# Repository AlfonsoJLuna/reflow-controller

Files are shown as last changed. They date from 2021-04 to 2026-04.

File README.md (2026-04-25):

# Reflow Controller

Open-source reflow controller for ovens and hot plates.

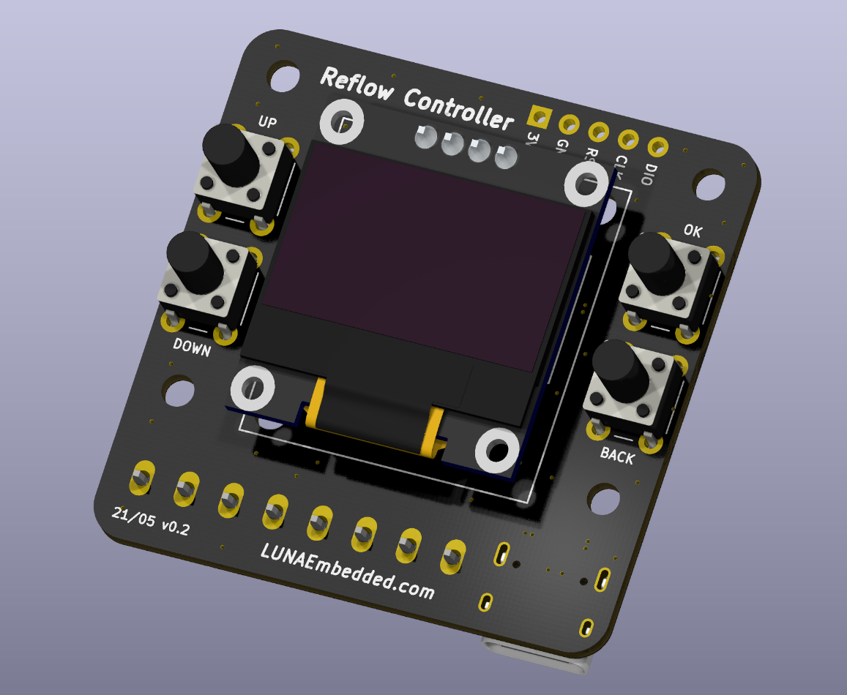
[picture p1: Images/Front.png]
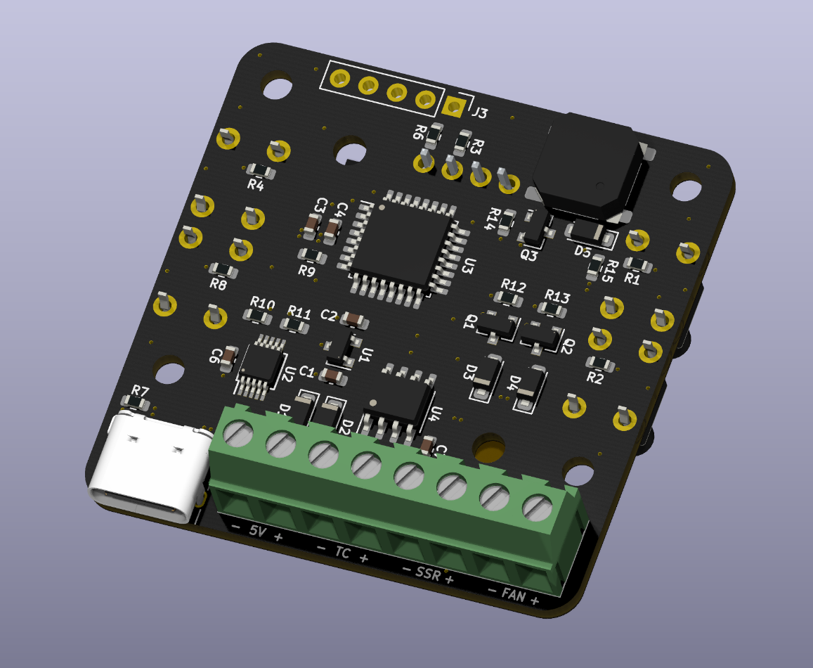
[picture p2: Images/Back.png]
 | 
:---: | :---:
Front | Back

## Features

* MCU: STM32G030K6T6
* CH340E USB-Serial converter.
* Sensors: K-Type thermocouple to digital converter. Compatible with both MAX31855 and MAX6675.
* Display: SSD1306 128×164 0.96" OLED.
* Inputs: 4x Push buttons to navigate the menu.
* Outputs: 2x 5V 300mA outputs. Capable of driving solid state relays as well as inductive loads (mechanical relays, fans).
* Buzzer: Alarm buzzer.
* Power: 5V provided via USB-C or screw terminals.

## Related repositories

Firmware for this project lives in [reflow-controller-fw](https://github.com/AlfonsoJLuna/reflow-controller-fw).

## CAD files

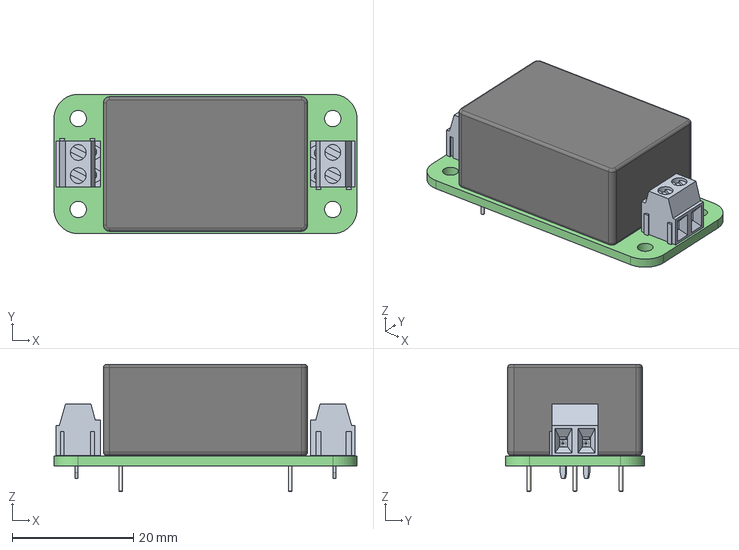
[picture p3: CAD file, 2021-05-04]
Hardware/AC-DC/AC-DC.step
50.0 x 23.0 x 21.0 mm

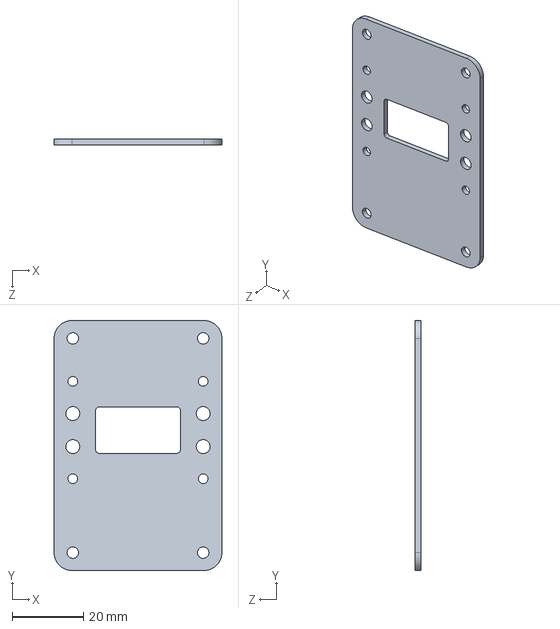
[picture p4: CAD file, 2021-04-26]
Hardware/Front Panel/Generic Oven/Generic_Oven.step
47.0 x 70.0 x 1.60 mm

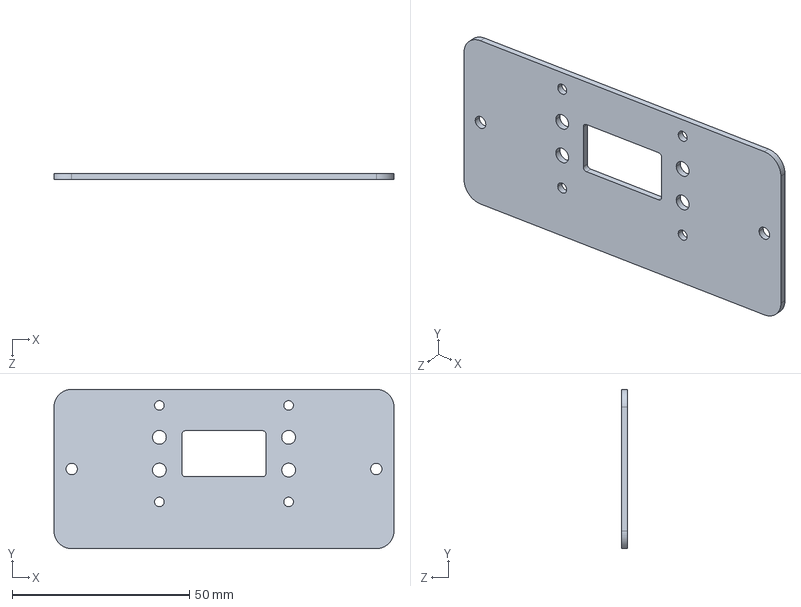
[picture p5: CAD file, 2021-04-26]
Hardware/Front Panel/Uyue 946-1010/Uyue_946_1010.step
96.0 x 45.0 x 1.60 mm

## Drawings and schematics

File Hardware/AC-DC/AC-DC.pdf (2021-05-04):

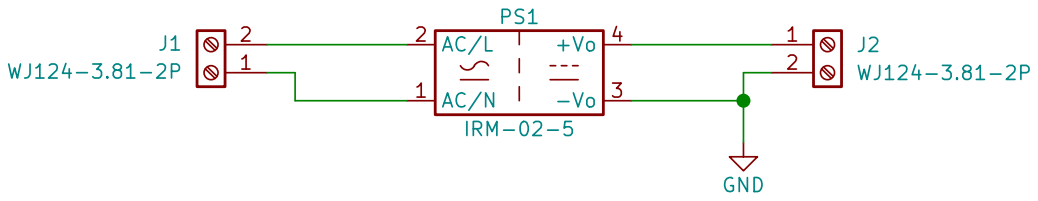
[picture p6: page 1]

File: AC-DC.sch Sheet: / LUNAEmbedded.com

Id: 1/1 Title: AC/DC Converter Module

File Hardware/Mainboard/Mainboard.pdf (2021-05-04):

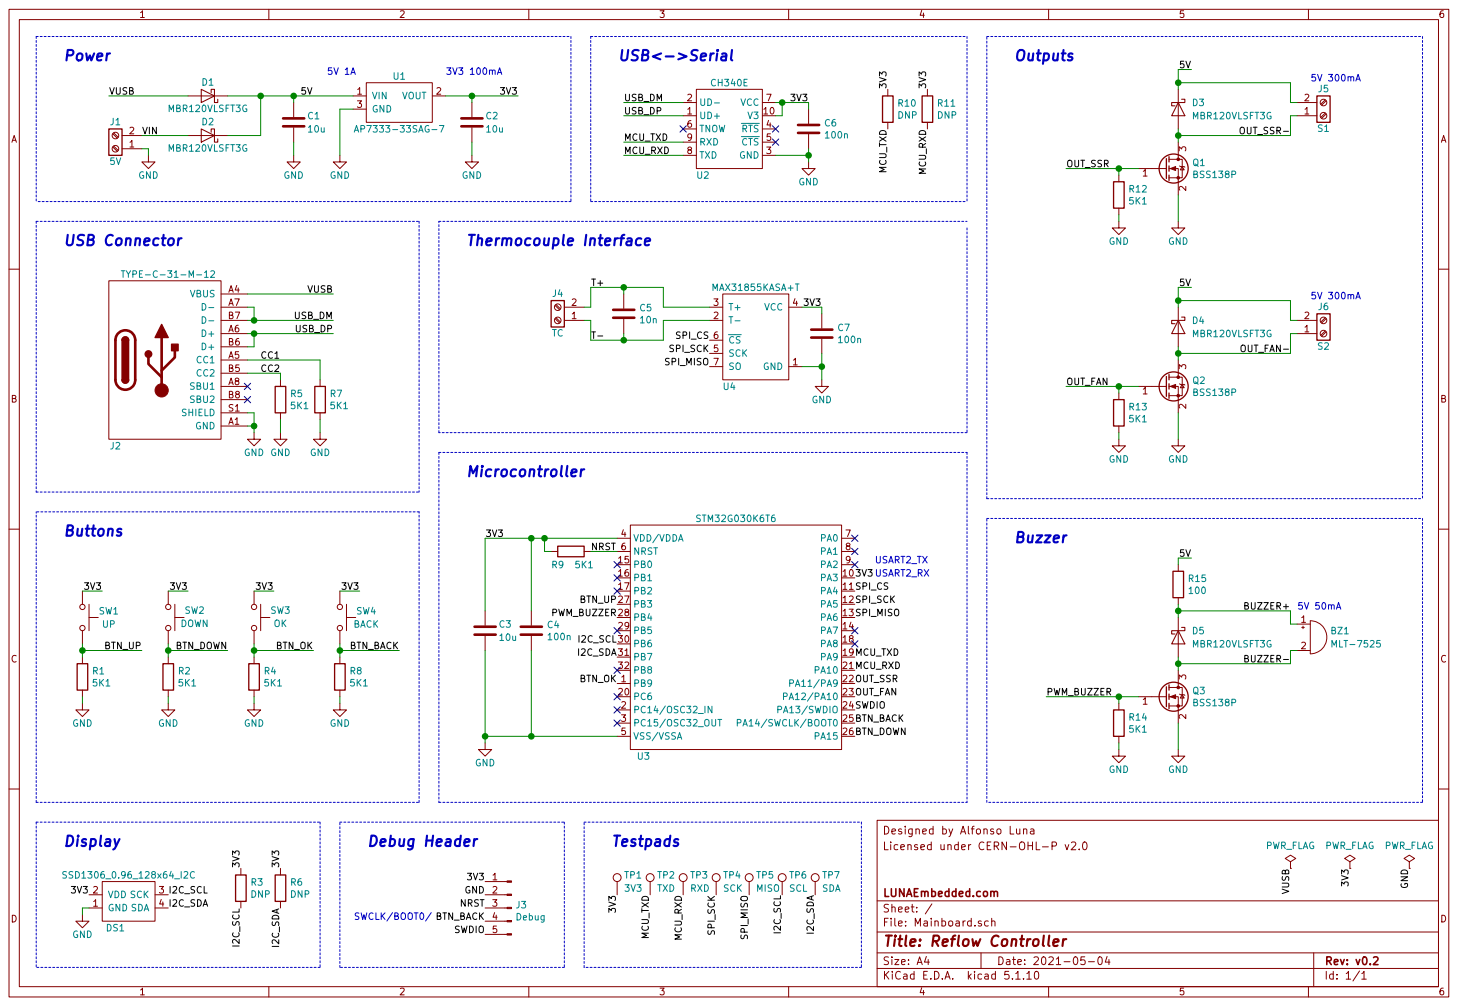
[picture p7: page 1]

Licensed under CERN-OHL-P v2.0 Designed by Alfonso Luna

Id: 1/1 Title: Reflow Controller File: Mainboard.sch Sheet: / LUNAEmbedded.com

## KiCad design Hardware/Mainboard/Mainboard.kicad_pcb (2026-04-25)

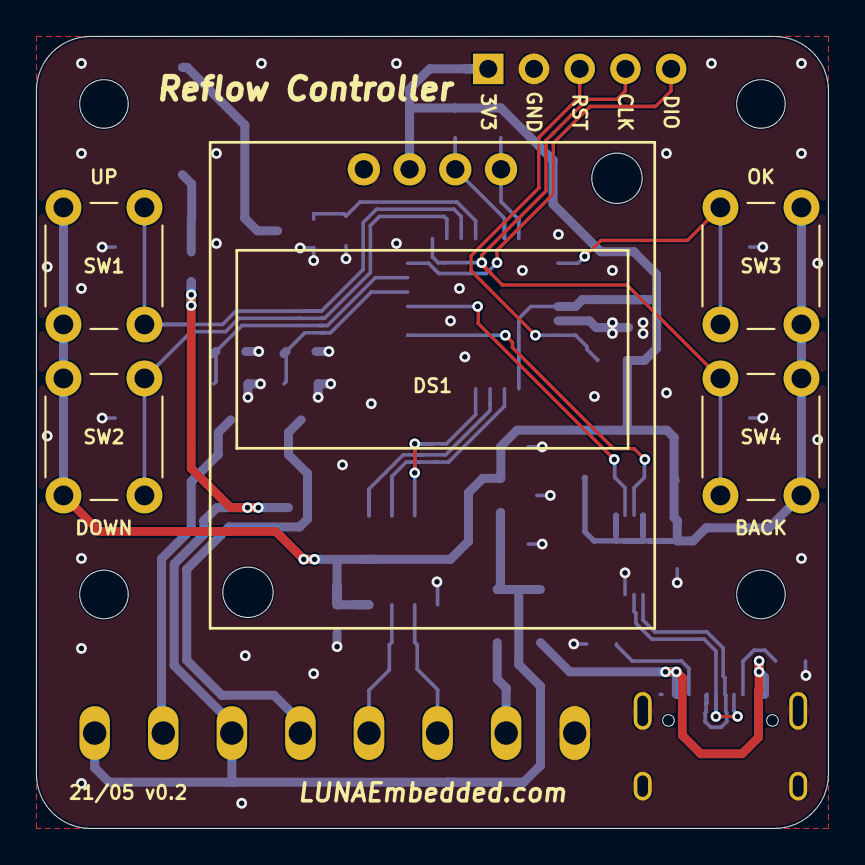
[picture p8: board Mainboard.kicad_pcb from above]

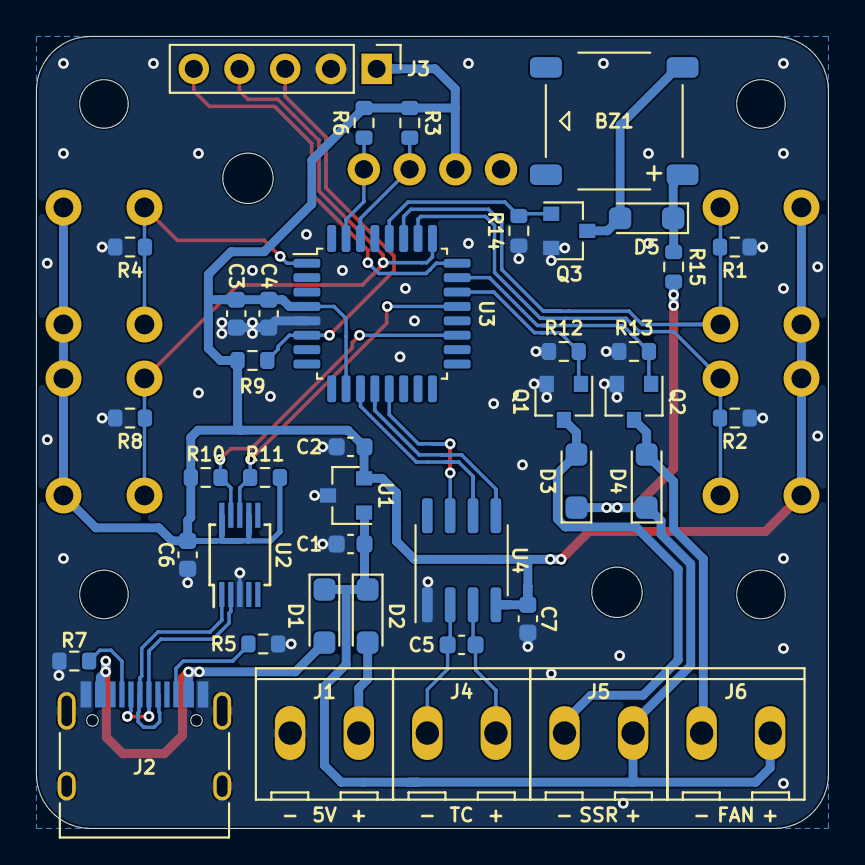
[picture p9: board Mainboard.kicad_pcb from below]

Board: 2 copper layers, 44.0 x 44.0 mm, 46 parts (41 on the bottom side), 31 nets.

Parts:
BZ1: MLT-7525
C1, C2, C3: 10u; C_0603_1608Metric
C4, C6, C7: 100n; C_0603_1608Metric
C5: 10n; C_0603_1608Metric
D1, D2, D3, D4, D5: MBR120VLSFT3G; SOD-123FL
DS1: SSD1306_0.96_128x64_I2C
J1: 5V; WJ124-3.81-2P
J2: TYPE-C-31-M-12; USB_C_Receptacle_HRO_TYPE-C-31-M-12
J3: Debug; PinHeader_1x05_P2.54mm_Vertical
J4: TC; WJ124-3.81-2P
J5: S1; WJ124-3.81-2P
J6: S2; WJ124-3.81-2P
Q1, Q2, Q3: BSS138P; SOT-23
R1, R2, R4, R5, R7, R8, R9, R12, R13, R14: 5K1; R_0603_1608Metric
R3, R6, R10, R11: DNP; R_0603_1608Metric
R15: 100; R_0603_1608Metric
SW1: UP; SW_PUSH_6mm_H9.5mm
SW2: DOWN; SW_PUSH_6mm_H9.5mm
SW3: OK; SW_PUSH_6mm_H9.5mm
SW4: BACK; SW_PUSH_6mm_H9.5mm
U1: AP7333-33SAG-7; SOT-23
U2: CH340E; MSOP-10_3x3mm_P0.5mm
U3: STM32G030K6T6; LQFP-32_7x7mm_P0.8mm
U4: MAX31855KASA+T; SOIC-8_3.9x4.9mm_P1.27mm

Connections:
/3V3: C2.1, C3.1, C4.1, C6.1, C7.1, DS1.2, J3.1, R3.1, R6.1, R9.2, R10.1, R11.1, SW1.1, SW2.2, SW3.2, SW4.1, U1.2, U2.7, U2.10, U3.4, U3.10, U4.4
/5V: C1.1, D1.1, D2.1, D3.1, D4.1, J5.2, J6.2, R15.1, U1.1
/BTN_BACK: J3.4, R8.1, SW4.2, U3.25
/BTN_DOWN: R2.1, SW2.1, U3.26
/BTN_OK: R4.1, SW3.1, U3.1
/BTN_UP: R1.1, SW1.2, U3.27
/BUZZER+: BZ1.1, D5.1, R15.2
/BUZZER-: BZ1.2, D5.2, Q3.3
/CC1: J2.A5, R7.1
/CC2: J2.B5, R5.1
/I2C_SCL: DS1.3, R3.2, U3.30
/I2C_SDA: DS1.4, R6.2, U3.31
/MCU_RXD: R11.2, U2.8, U3.21
/MCU_TXD: R10.2, U2.9, U3.19
/NRST: J3.3, R9.1, U3.6
/OUT_FAN: Q2.1, R13.1, U3.23
/OUT_FAN-: D4.2, J6.1, Q2.3
/OUT_SSR: Q1.1, R12.1, U3.22
/OUT_SSR-: D3.2, J5.1, Q1.3
/PWM_BUZZER: Q3.1, R14.1, U3.28
/SPI_CS: U3.11, U4.6
/SPI_MISO: U3.13, U4.7
/SPI_SCK: U3.12, U4.5
/SWDIO: J3.5, U3.24
/T+: C5.1, J4.2, U4.3
/T-: C5.2, J4.1, U4.2
/USB_DM: J2.A7, J2.B7, U2.2
/USB_DP: J2.A6, J2.B6, U2.1
/VIN: D2.2, J1.2
/VUSB: D1.2, J2.A4, J2.A9, J2.B4, J2.B9
GND: C1.2, C2.2, C3.2, C4.2, C6.2, C7.2, DS1.1, J1.1, J2.A1, J2.A12, J2.B1, J2.B12, J2.S1, J3.2, Q1.2, Q2.2, Q3.2, R1.2, R2.2, R4.2, R5.2, R7.2, R8.2, R12.2, R13.2, R14.2, U1.3, U2.3, U3.5, U4.1

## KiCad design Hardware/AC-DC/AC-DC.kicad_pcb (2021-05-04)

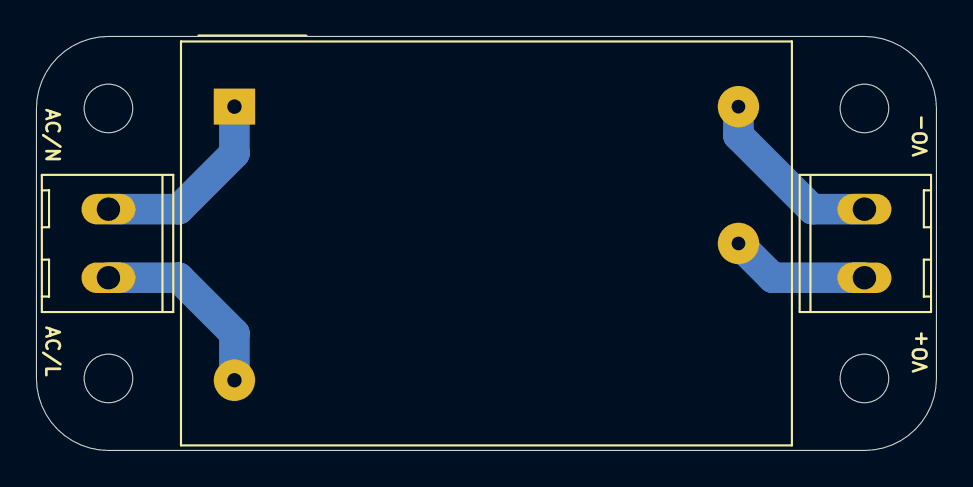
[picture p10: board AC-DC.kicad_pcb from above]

Board: 2 copper layers, 50.0 x 23.0 mm, 4 parts (1 on the bottom side), 4 nets.

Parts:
J1, J2: WJ124-3.81-2P
PS1: IRM-02-5; Converter_ACDC_MeanWell_IRM-02-xx_THT
r: OSHW-Logo_5.7x6mm_SilkScreen

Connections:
GND: J2.2, PS1.3
unnamed: J1.1, PS1.1
unnamed: J1.2, PS1.2
unnamed: J2.1, PS1.4

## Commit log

2020-12-24 Finished schematics
    [reflow-oven.kicad_pcb, reflow-oven.sch]
2020-12-25 Finished PCB layout
    [reflow-oven-B_Cu.gbr, reflow-oven-B_Mask.gbr, reflow-oven-B_Paste.gbr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]
2021-01-23 Added pdf schematics
2021-02-22 Updated readme, added interactive BOM
2021-02-22 Updated interactive BOM link
2021-02-23 Configurable temperature offset
2021-02-27 Added PID control
2021-03-04 Added enclosure FreeCAD and STL files
    [Trasera.FCStd, botones.FCStd, botones.stl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]
2021-04-07 Improved profiles, configurable buzzer beeps
    [Profile Spreadsheet.xlsx]
2021-04-09 Improved default PID parameters, added PID tuner, added Simulink model
    [PID_Tuner_Plate.xlsx, Profile Spreadsheet.xlsx, Profiles.xlsx]
2021-04-11 Added AC/DC module
    [AC-DC.kicad_pcb, AC-DC.sch, Mainboard.kicad_pcb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]
2021-04-26 v0.2: Finished schematics
    [Generic_Oven.kicad_pcb, Generic_Oven.step, Mainboard.kicad_pcb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]
2021-04-26 v0.2: Preliminary placement
    [Mainboard.kicad_pcb, Mainboard.sch]
2021-04-28 v0.2: Updated placement
    [Mainboard.kicad_pcb, Mainboard.sch]
2021-05-04 v0.2: Finished PCBs
    [AC-DC-B_Cu.gbr, AC-DC-B_Mask.gbr, AC-DC-B_Paste.gbr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]
2021-05-04 v0.2: KiKit panels
    [AC-DC-B_Cu.gbr, AC-DC-B_Mask.gbr, AC-DC-B_Paste.gbr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]
2021-05-05 v0.2: Modified Uyue-946-1010 front panel
    [Uyue_946_1010.kicad_pcb]
2022-01-21 v0.1: Updated MAX31855 and MAX6675 SPI driver so the temperature can be read even in presence of TC shorted to GND/VCC errors
2026-04-24 Updated folder structure
    [AC-DC.kicad_pcb, AC-DC.sch, AC-DC.step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]
2026-04-25 Removed v0.1 files as now there is a v0.1 tag
    [AC-DC.kicad_pcb, AC-DC.sch, AC-DC.step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]
2026-04-25 Updated project files to KiCad 10
    [Mainboard.kicad_pcb, Mainboard.kicad_sch, Mainboard.sch]
2026-04-25 Updated readme and images
    [AC-DC.kicad_pcb, AC-DC.sch, AC-DC.step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]
